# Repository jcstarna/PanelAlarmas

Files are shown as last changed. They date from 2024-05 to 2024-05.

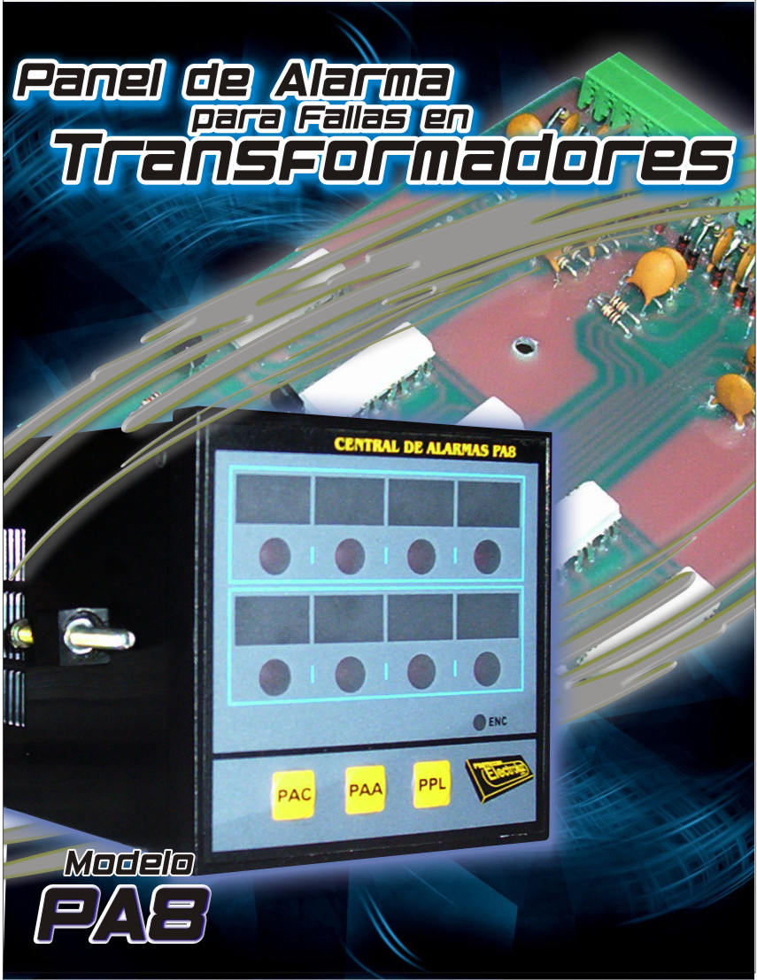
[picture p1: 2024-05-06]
docs/central de alarmas.jpg

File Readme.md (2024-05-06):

# Panel de Alarmas

Panel de Alarmas

## Requisitos
+ Puglin MPLAB 'CCS C Compiler' instalado. (Tools -> Plugins) 
+ Compilador CCS version 5.093 instalado en el sistema

## Verificar
+ Verificar que las rutas sean correctas en:  Project  -> Properties -> Conf: [nombre] -> CCS C Compiler -> Compiler Options -> Include Directoies

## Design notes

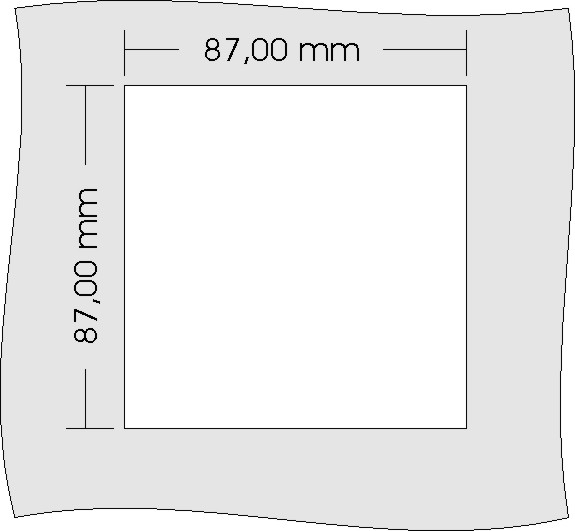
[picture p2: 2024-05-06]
docs/corte.jpg

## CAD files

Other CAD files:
docs/PA8.dwg

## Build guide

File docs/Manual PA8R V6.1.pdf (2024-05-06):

1

# PANEL DE ALARMAS

### DESCRIPCIÒN:

Los paneles de alarmas PA8R ofrecen una solución compacta y confiable para el manejo de alarmas de estaciones transformadoras o instalaciones que precisen indicación lumínica y sonora de fallas.
Cuenta con comunicación MODBUS RTU, que permite visualizar desde una PC el estado de fallas A1 – A8, Aparecida, Desaparecida o Aceptada. Estos paneles de Alarmas cuentan internamente con los Relay de disparo para los interruptores, las indicaciones de Alarmas están formadas por los cuatro leds superiores y los de Disparo por los cuatro inferiores.

Las entradas se encuentran aisladas ópticamente, para la salida de campana el panel cuenta con un Relay de 3 Amp en 220 Vca.

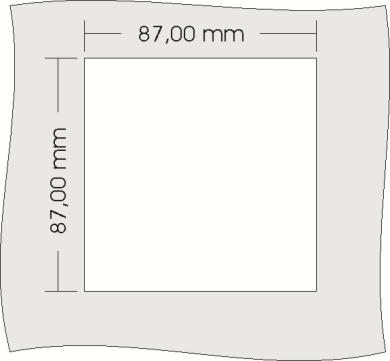
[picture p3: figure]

### MONTAJE:

Diseñadas para su instalación en panel. Solo requiere un calado de 87 x 87mm.
Como se muestra en la figura.

### CONEXIONES:

Se realizan con tres borneras enchufables para mayor comodidad.

X1: Alimentación (24Vcc o 220Vca según Modelo) + Rele de campana. X2: Entradas (24Vcc o 220Vca según Modelo).
X3: Puerto de Comunicación.

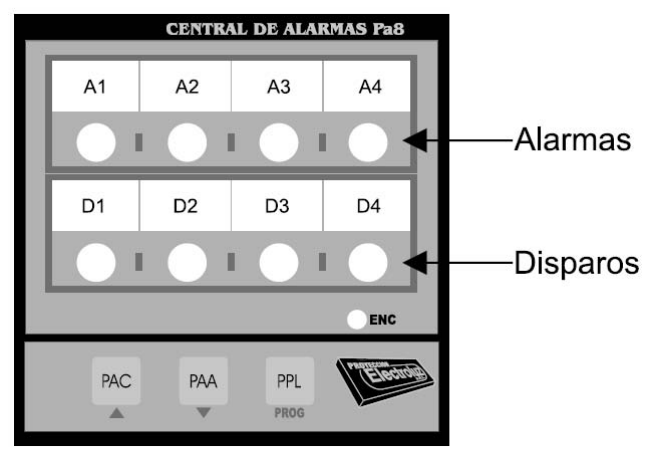
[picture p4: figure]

El diagrama de conexionado se muestra en la Figura 2.

### CONFIGURACIÒN:

Es necesario configurar la dirección del panel para comunicarse con una PC, las direcciones configurables van desde la 1 (por defecto) a la 255.

Procedimiento para la configuración:
1) Energizar el panel de alarmas manteniendo presionada la tecla PROG (PPL), hasta que titile el LED de ENC (aproximadamente 1Sec.)
2) El Panel indicara la dirección configurada. Use las teclas (PAC) y (PPL), para modificar la dirección y lograra la deseada.
3) Una vez seleccionada la nueva dirección presione PROG (PPL) y el panel tendrá ahora la nueva dirección. Para Cancelar simplemente se desenergiza el panel y se vuelve a energizar.

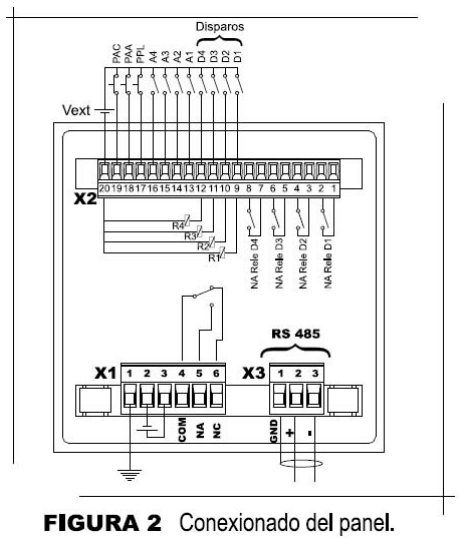
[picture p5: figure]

Forma de indicación de dirección:
El panel muestra la dirección en forma binaria, separado en nibles, el nible alto con los cuatro LED superiores y el nible bajo con los cuatro LED inferiores. Figura 3

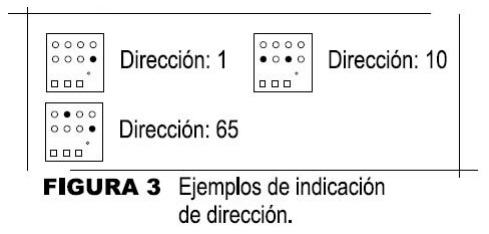
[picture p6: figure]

2

LOGICA DE FUNCIONAMIENTO:

Al aparecer una alarma o disparo, el led correspondiente comenzara a titilar, también se activara la salida para campana, esta situación se mantendrá hasta que se presione el botón de aceptación de campana (PAC), al hacer esto, el relay de campana se desactiva y continua titilando el led correspondiente, para aceptar la alarma, se debe presionar el botón de aceptación de alarma (PAA), con esto, si el disparo o alarma todavía esta presente, el led deja de titilar y queda encendido, si el evento que produjo la alarma desapareció, el led se apaga al presionar (PAA), si la alarma continua presente, el led continuara encendido hasta que la falla desaparezca.
No podrá aceptar la alarma sin antes aceptar la campana.

Registros ModBus:
Es posible conocer los estados de las distintas alarmas, y aceptar alarmas a través de los registros. Esto se logra accediendo a los mismos, para ello debe usarse el comando ModBus 0x03 Read Holding Registers, Para ello el equipo dispone de 15 words, 40001 a 40015, las mismas contienen la siguiente información:

40001: Reservado
40002: Comando
40003: Tiempo filtrado entrada Alarma1 x 10ms
40004: Tiempo filtrado entrada Alarma2 x 10ms 40005: Tiempo filtrado entrada Alarma3 x 10ms 40006: Tiempo filtrado entrada Alarma4 x 10ms 40007: Tiempo filtrado entrada Disparo1 x 10ms 40008: Tiempo filtrado entrada Disparo2 x 10ms 40009: Tiempo filtrado entrada Disparo3 x 10ms 40010: Tiempo filtrado entrada Disparo4 x 10ms 40011: Estado Alarma1 : Estado Alarma2 40012: Estado Alarma3 : Estado Alarma4 40013: Estado Disparo1 : Estado Disparo2 40014: Estado Disparo3 : Estado Disparo4
40015: Tiempo de autoreset campana x 500ms

Interpretación del estado:
El byte de estado de la alarma puede tener 3 valores.

0: Normal
1: Alarma aparecida y no aceptada.
2: Alarma aparecida, aceptada y presente.

Comando:
Es posible aceptar las fallas y detener la campana a través de modbus, esto se logra escribiendo los siguientes comandos:

1: Acepta campana, tiene el mismo efecto que pulsar el botón PAC.
2: Acepta las fallas, tiene el mismo efecto que pulsar el botón PAA

Luego de ejecutado el comando la central pone a cero este registro.

Autoreset de campana:

Es posible configurar la central, para que pasado cierto tiempo la campana deje de sonar, esto se logra escribiendo en el registro 40015 un valor distingo de cero, cuando aparezca una alarma, se dispara la campana y corre el tiempo de autoreset, esto se indica con el led de encendido oscilando, pasado el tiempo configurado, la campana se resetea.

Configuración Velocidad:

El panel admite 2 velocidades de comunicación 9600 y 19200, esto se configura con el numero de esclavo, un numero de esclavo entre 1 y 127 funciona con 9600 bps de velocidad en el puerto, para valores mayores a 127 la velocidad es 19200 bps y el numero de esclavo se obtiene restando 127 a la dirección configurada.

Ej. Dirección 10, la central funcionara con 9600 bps y dirección de esclavo 10.
Ej. Dirección 129, la central funcionara con 19200 bps y dirección de esclavo 2 -> 129-127=2.

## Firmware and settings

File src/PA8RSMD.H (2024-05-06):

////////////////////////////////////////////////////////////////////////////////
////                   PANEL DE ALARMAS PA8R SMD
//                            VARIABLES
////FECHA:31/07/2012
////REVISION: 1.00
////AUTOR:CRTARG
////////////////////////////////////////////////////////////////////////////////

//******************************************************************************
//  NOTAS REVISIONES:
//
/*
Ver: 1.00
   Version inicial
*/

//PUERTO A
#DEFINE  pLed     PIN_A1   //LED DE ENCENDIDO/CONFIG
#DEFINE  pMax485  PIN_A3   //AUTORIZACION DE TRANSMISION
#DEFINE  pAlarma  PIN_A5   //SALIDA RELE DE ALARMA


//PUERTO B
//PUERTO MULTIPLEXADO

//PUERTO C
#define  pMux1    PIN_C0
#define  pMux2    PIN_C1
#define  pG       PIN_C2
#DEFINE  pSER     PIN_C3
#define  pRCK     PIN_C4
#define  pSCK     PIN_C5

int const k10ms=10;
int const k05s=24;//50

//direcciones datos en EEPROM
int const kAddress=0;
int const krpA1=1;
int const krpA2=2;
int const krpA3=3;
int const krpA4=4;
int const krpD1=5;
int const krpD2=6;
int const krpD3=7;
int const krpD4=8;
int const kEstAl=9;  //estado del panel
int const kTrAl=10;  //tiempo de autoreset alarma 0 - no autoreset
int const kPreBTAl=11;

//VARIABLES
//FLAGS
int1  f05seg=0;//pulso de 1/2 segundo
int1  fProg=0;
int1  fPAC=0;  //Paralelo pulsadores
int1  fPAA=0;  //IDEM
int1  fPPL=0;  //idem
int1  fMdbPAA=0;  //PAA via modbus
int1  fMdbPAC=0;  //PAC via modbus
int1  fBusInact=0;
int1  fCampana=0;
int1  fAutoRes=0;
int1  fEscEEPROM=0;

//Tiempos
int rTmr10ms=0;//contador para llegar a 10ms
int rTmr05s=0; //contador para llegar a 500ms
int rTiempos=0;//registros con bits de tiempo
int rBTAl=1;   //Base de tiempo para alarma  
int rAuxBTAl=0;//auxiliar

//De Comunicacion
//INT RX_buff[10];
//INT TX_buff[10];
int RX_index=0;
int TX_index=0;
int rTmrBus=0; //tiempo de inactividad del bus
INT rSpTmrBus=5;  //tiempo de inact del bus, depende del baud rate


//De alarmas
int rAlarmas=0;//rAlarmas
int rEstAntAl=0;
int rFpAl=0;
int rFpAlTemp=0;
int rMAux=0;//marcas auxiliares para leds
int rLeds=0;//registro imagen de leds del frente
int rTempLed=0;
int rA1=0;
int rA2=0;
int rA3=0;
int rA4=0;
int rD1=0;
int rD2=0;
int rD3=0;
int rD4=0;
int rTrAl=0;

//Registros Modbus
int16 rEstado=1;     // rEstado
int16 rComando=2;    // 40002 
int16 rpA1=10;       // 40003
int16 rpA2=10;       // 40004
int16 rpA3=10;       // 40005
int16 rpA4=10;       // 40006
int16 rpD1=10;       // 40007
int16 rpD2=10;       // 40008
int16 rpD3=10;       // 40009
int16 rpD4=10;       // 40010
int eA1=0;           // 40011        
int eA2=0;           // 
int eA3=0;           // 40012
int eA4=0;           // 
int eA5=0;           // 40013
int eA6=0;           // 
int eA7=0;           // 40014
int eA8=0;           // 
int16 rSpTrAl=0;     // 40015
int16 rPreBTAl=0;    // 40016
int16 rBtn=0;        //




//bit alarmas (lectura fisica filtrada)
#bit     pD1   =  rAlarmas.4  //2
#bit     pD2   =  rAlarmas.5  //1
#bit     pD3   =  rAlarmas.6  //0
#bit     pD4   =  rAlarmas.7  //7  
#bit     pA1   =  rAlarmas.0  //3
#bit     pA2   =  rAlarmas.1  //4
#bit     pA3   =  rAlarmas.2  //5
#bit     pA4   =  rAlarmas.3  //6

//bits en palabra estado
#bit     fD1   =  rEstado.4
#bit     fD2   =  rEstado.5
#bit     fD3   =  rEstado.6
#bit     fD4   =  rEstado.7
#bit     fA1   =  rEstado.0
#bit     fA2   =  rEstado.1
#bit     fA3   =  rEstado.2
#bit     fA4   =  rEstado.3

//bits flancos positivos
#bit     fpD1   =  rFpAl.4
#bit     fpD2   =  rFpAl.5
#bit     fpD3   =  rFpAl.6
#bit     fpD4   =  rFpAl.7
#bit     fpA1   =  rFpAl.0
#bit     fpA2   =  rFpAl.1
#bit     fpA3   =  rFpAl.2
#bit     fpA4   =  rFpAl.3
